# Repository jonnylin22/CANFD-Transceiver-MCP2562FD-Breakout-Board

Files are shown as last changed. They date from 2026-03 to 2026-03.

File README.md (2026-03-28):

# CAN-FD Transceiver MCP2562FD Breakout Board #

This board lays out the Microchip Technology MCP2562FD CAN-FD Transceiver IC onto a board to create an external breakout board style CAN physical layer for MCUs with an embedded CAN controller but no transceiever.  

Exact Reference Manufacturer Product Number: MCP2562FD-E/SN  

## Final Boards 3D Renders ##  
CANFD Breakout with Spring Terminals Top Side  
CANFD Breakout with Spring Terminals Bottom Side

CANFD Breakout with JST-PH3 Connector Top Side
CANFD Breakout with JST-PH3 Connector Bottom Side

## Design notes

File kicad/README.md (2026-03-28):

# Directory for everything KiCad #  

The file named gerbers.zip stores the most up to date generated PCB manufacturing files.  
The folder named version2-with-JST-PH3/ ustilizes a JST-PH3 connector with the same components.

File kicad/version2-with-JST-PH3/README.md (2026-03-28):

# CAN-FD Transceiver Breakout Board #  

This is a board with the same components except that it is routed to a JST-PH3 right angle horizontal connector to allow for use of JST-PH3 cables for the CAN bus

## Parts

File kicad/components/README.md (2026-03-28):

# Component Library for KiCad Schematic and PCB #  

3D models are in models/  
PCB layout footprints are in footprints/  
Schematic design symbols are in symbols/

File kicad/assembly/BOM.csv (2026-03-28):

Reference | Qty | Value | Footprint | Datasheet | Manufacturer_Name | Manufacturer_Part_Number | LCSC_Part_Number
C1,C3 | 2 | 100n | Capacitor_SMD:C_0603_1608Metric_Pad1.08x0.95mm_HandSolder | ~ | Samsung Electro-Mechanics | CL10E104KC8VPNC | C16194197
C2 | 1 | 4.7n | Resistor_SMD:R_0402_1005Metric_Pad0.72x0.64mm_HandSolder | ~ | KEMET | C0402C472J5RACTU | C2167398
D1,D2 | 2 | LED | LED_SMD:LED_0603_1608Metric_Pad1.05x0.95mm_HandSolder | ~ | LITEON | LTST-C191KRKT | C125099
D3 | 1 | CDSOT23-T24CAN | CanFD-Transceiver-FP-Lib:SOT95P230X117-3N | https://www.bourns.com/docs/Product-Datasheets/CDSOT23-T24CAN.pdf | Bourns | CDSOT23-T24CAN
J2 | 1 | 1862042 | CanFD-Transceiver-FP-Lib:1862042 | https://www.phoenixcontact.com/en-us/products/printed-circuit-board-terminal-sptaf-1-2-35-el-1862042?type=pdf | Phoenix Contact | 1862042
R1,R2 | 2 | 60R | Resistor_SMD:R_0402_1005Metric_Pad0.72x0.64mm_HandSolder | ~ | YAGEO | RC0402FR-0762RL | C274896
R3,R4 | 2 | 2k2 | Resistor_SMD:R_0603_1608Metric_Pad0.98x0.95mm_HandSolder | ~ | YAGEO | RC0603FR-072K2L | C114662
U1 | 1 | MCP2562FD-E_SN | CanFD-Transceiver-FP-Lib:SOIC127P600X175-8N | https://ww1.microchip.com/downloads/aemDocuments/documents/OTH/ProductDocuments/DataSheets/20005284A.pdf | Microchip | MCP2562FD-E/SN

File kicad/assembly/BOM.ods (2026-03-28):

Reference | Qty | Value | DNP | Exclude from BOM | Exclude from Board | Footprint | Datasheet | Manufacturer_Name | Manufacturer_Part_Number | LCSC_Part_Number
C1,C3 | 2 | 100n |  |  |  | Capacitor_SMD:C_0603_1608Metric_Pad1.08x0.95mm_HandSolder | ~ | Samsung Electro-Mechanics | CL10E104KC8VPNC | C16194197
C2 | 1 | 4.7n |  |  |  | Resistor_SMD:R_0402_1005Metric_Pad0.72x0.64mm_HandSolder | ~ | KEMET | C0402C472J5RACTU | C2167398
D1,D2 | 2 | LED |  |  |  | LED_SMD:LED_0603_1608Metric_Pad1.05x0.95mm_HandSolder | ~ | LITEON | LTST-C191KRKT | C125099
D3 | 1 | CDSOT23-T24CAN |  |  |  | CanFD-Transceiver-FP-Lib:SOT95P230X117-3N | https://www.bourns.com/docs/Product-Datasheets/CDSOT23-T24CAN.pdf | Bourns | CDSOT23-T24CAN
FD1 | 1 | FIDUCIAL | DNP | Excluded from BOM | Excluded from board | Fiducial:Fiducial_0.5mm_Mask1mm
H1,H3 | 2 | HOLE_2.2mm |  | Excluded from BOM |  | MountingHole:MountingHole_2.2mm_M2_DIN965_Pad_TopBottom | ~
J2 | 1 | 1862042 |  | Excluded from BOM |  | CanFD-Transceiver-FP-Lib:1862042 | https://www.phoenixcontact.com/en-us/products/printed-circuit-board-terminal-sptaf-1-2-35-el-1862042?type=pdf | Phoenix Contact | 1862042
JP1 | 1 | Jumper_2_Small_Open |  | Excluded from BOM |  | Jumper:SolderJumper-2_P1.3mm_Open_RoundedPad1.0x1.5mm | ~
JP2 | 1 | SolderJumper_3_Open |  | Excluded from BOM |  | Jumper:SolderJumper-3_P1.3mm_Open_Pad1.0x1.5mm_NumberLabels | ~
K1 | 1 | HEADER_MALE_6X1 |  | Excluded from BOM |  | Connector_PinHeader_2.54mm:PinHeader_1x06_P2.54mm_Horizontal
R1,R2 | 2 | 60R |  |  |  | Resistor_SMD:R_0402_1005Metric_Pad0.72x0.64mm_HandSolder | ~ | YAGEO | RC0402FR-0762RL | C274896
R3,R4 | 2 | 2k2 |  |  |  | Resistor_SMD:R_0603_1608Metric_Pad0.98x0.95mm_HandSolder | ~ | YAGEO | RC0603FR-072K2L | C114662
U1 | 1 | MCP2562FD-E_SN |  |  |  | CanFD-Transceiver-FP-Lib:SOIC127P600X175-8N | https://ww1.microchip.com/downloads/aemDocuments/documents/OTH/ProductDocuments/DataSheets/20005284A.pdf | Microchip | MCP2562FD-E/SN

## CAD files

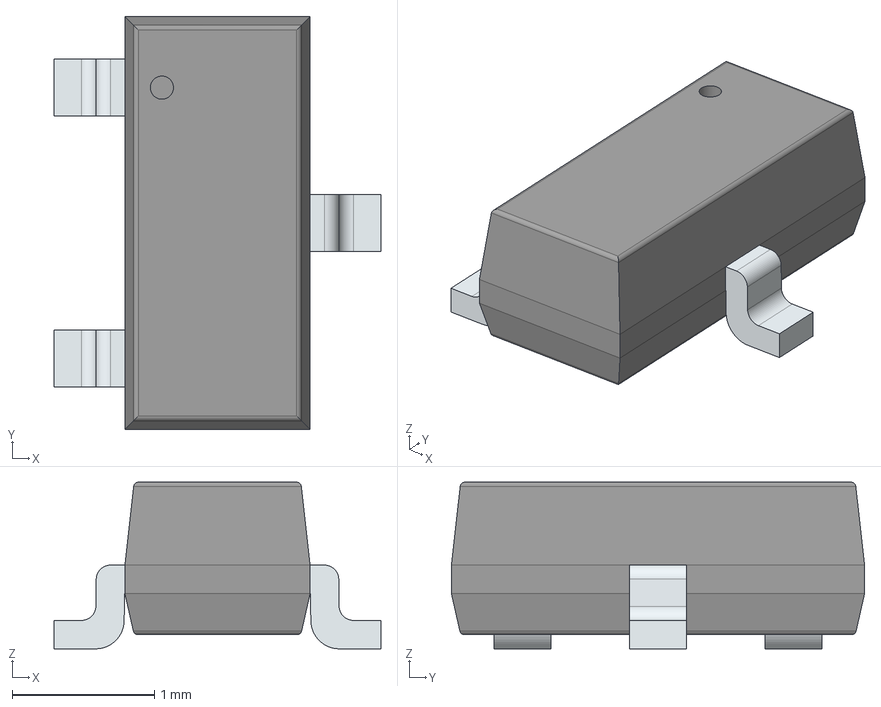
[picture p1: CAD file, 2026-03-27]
kicad/version2-with-JST-PH3/components/models/CDSOT23-T24CAN.stp
2.29 x 2.90 x 1.17 mm
PinsArrayL
FilletPinR

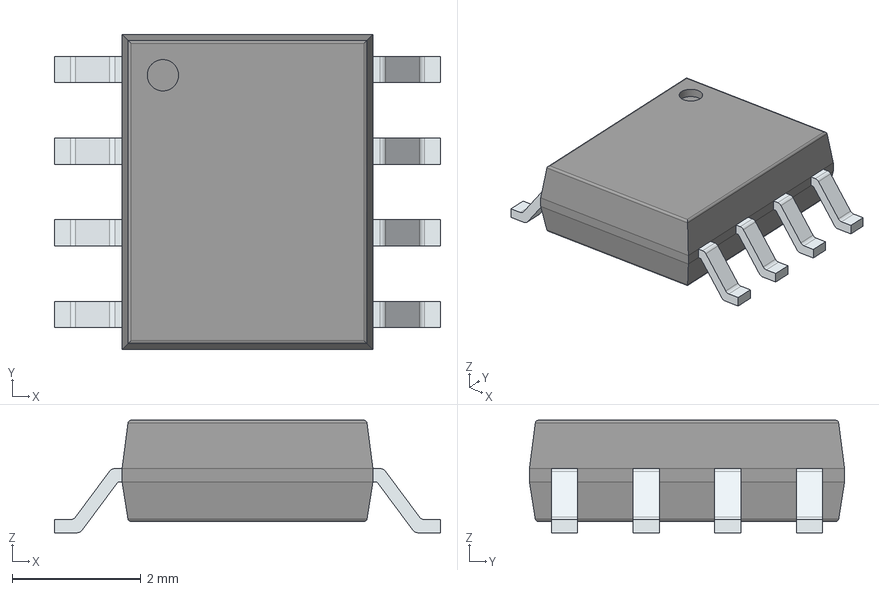
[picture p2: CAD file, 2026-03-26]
kicad/version2-with-JST-PH3/components/models/MCP2562FD-E_SN.stp
6.00 x 4.90 x 1.75 mm
PinsArrayLR

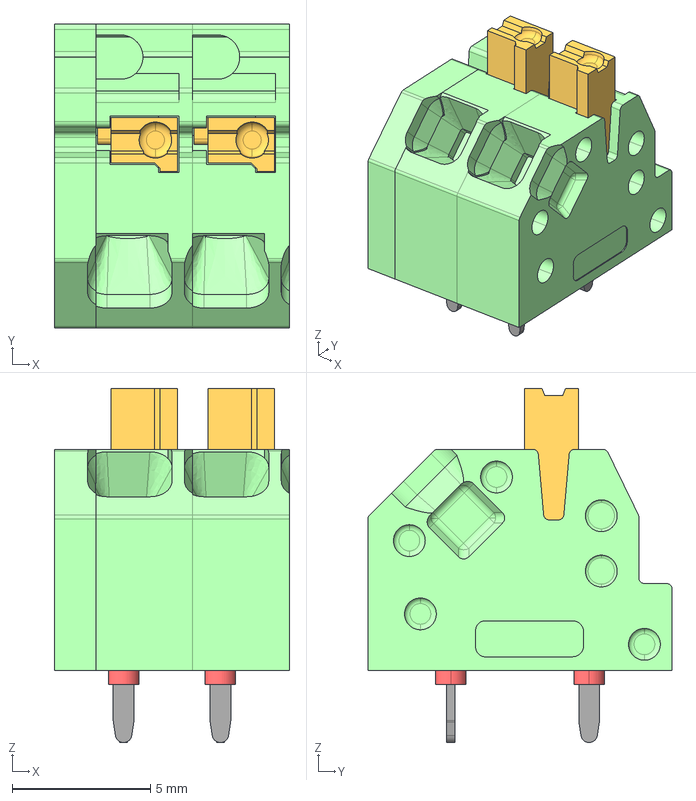
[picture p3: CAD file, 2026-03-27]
kicad/version2-with-JST-PH3/components/models/1862042.stp
8.50 x 11.0 x 12.8 mm
Bohrloch.1.1 x 2
Bohrloch.2 x 2
SPTAF_1-3.5_housing x 2
SPTAF-0-DKL.1

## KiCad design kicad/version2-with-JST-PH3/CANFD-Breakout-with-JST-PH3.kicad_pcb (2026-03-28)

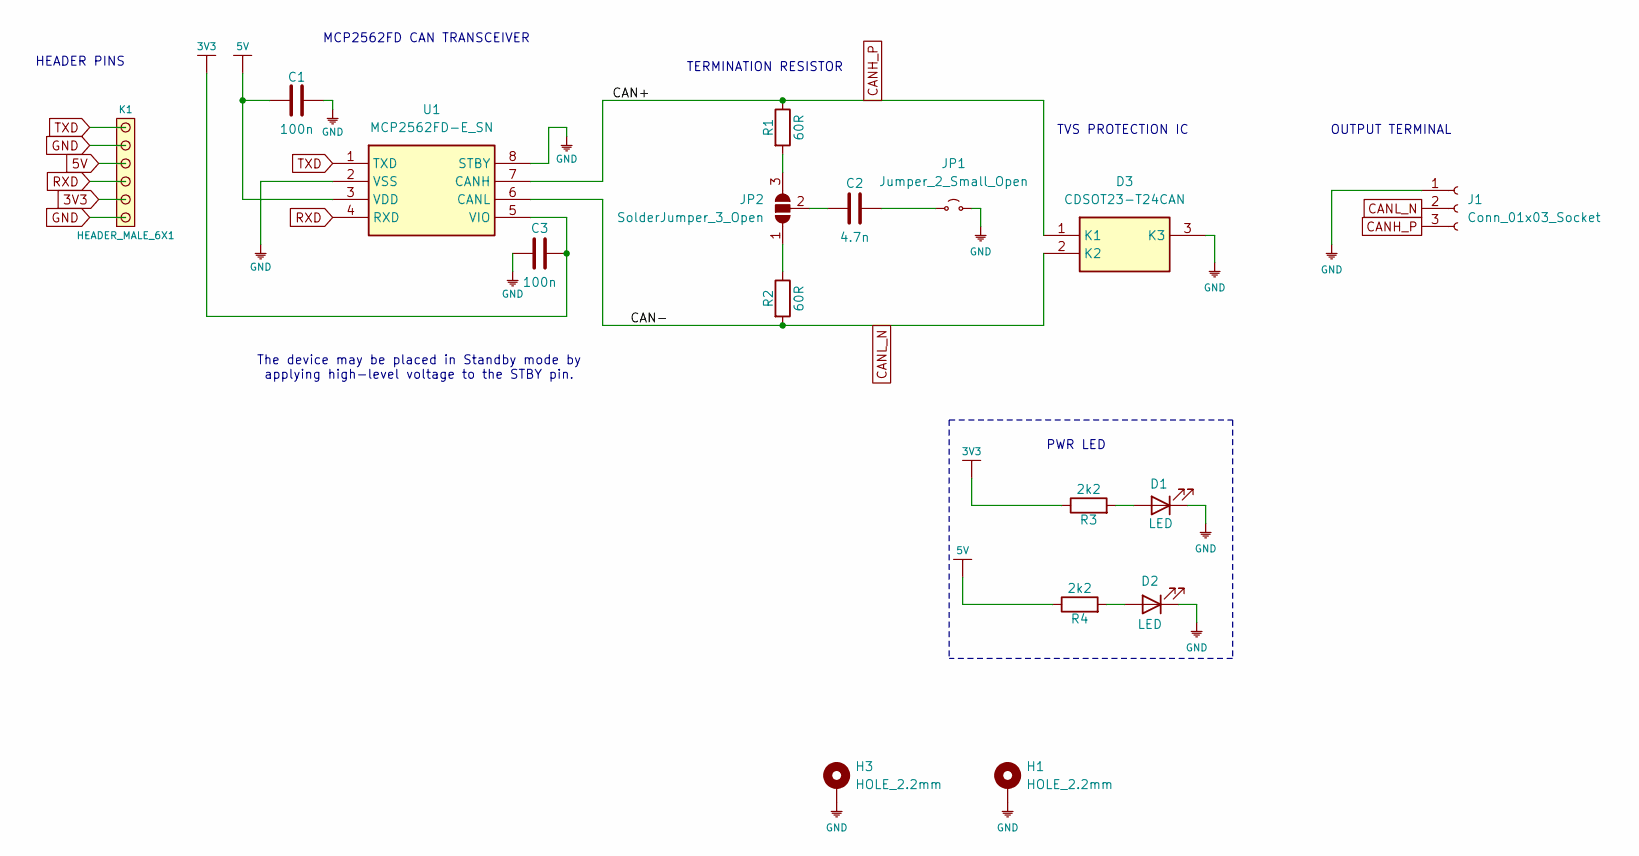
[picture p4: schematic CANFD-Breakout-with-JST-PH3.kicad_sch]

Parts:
C1, C3: 100n; C_0603_1608Metric_Pad1.08x0.95mm_HandSolder; Manufacturer_Part_Number CL10E104KC8VPNC; LCSC_Part_Number C16194197
C2: 4.7n; R_0402_1005Metric_Pad0.72x0.64mm_HandSolder; Manufacturer_Part_Number C0402C472J5RACTU; LCSC_Part_Number C2167398
D1, D2: LED; LED_0603_1608Metric_Pad1.05x0.95mm_HandSolder; Manufacturer_Part_Number LTST-C191KRKT; LCSC_Part_Number C125099
D3: CDSOT23-T24CAN; SOT95P230X117-3N; Mouser Part Number 652-CDSOT23-T24CAN
H1, H3: HOLE_2.2mm; MountingHole_2.2mm_M2_DIN965_Pad_TopBottom
J1: Conn_01x03_Socket; JST_PH_S3B-PH-K_1x03_P2.00mm_Horizontal
JP1: Jumper_2_Small_Open; SolderJumper-2_P1.3mm_Open_RoundedPad1.0x1.5mm
JP2: SolderJumper_3_Open; SolderJumper-3_P1.3mm_Open_Pad1.0x1.5mm_NumberLabels
K1: HEADER_MALE_6X1; PinHeader_1x06_P2.54mm_Horizontal
R1, R2: 60R; R_0402_1005Metric_Pad0.72x0.64mm_HandSolder; Manufacturer_Part_Number RC0402FR-0762RL; LCSC_Part_Number C274896
R3, R4: 2k2; R_0603_1608Metric_Pad0.98x0.95mm_HandSolder; Manufacturer_Part_Number RC0603FR-072K2L; LCSC_Part_Number C114662
U1: MCP2562FD-E_SN; SOIC127P600X175-8N; Mouser Part Number 579-MCP2562FD-E/SN

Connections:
3V3: C3.2, K1.2, R3.1, U1.5 (VIO)
5V: C1.1, K1.4, R4.1, U1.3 (VDD)
CANH_P: D3.1 (K1), J1.3, R1.1, U1.7 (CANH)
CANL_N: D3.2 (K2), J1.2, R2.2, U1.6 (CANL)
GND: C1.2, C3.1, D1.1 (K), D2.1 (K), D3.3 (K3), H1.1, H3.1, J1.1, JP1.2 (B), K1.1, K1.5, U1.2 (VSS), U1.8 (STBY)
unnamed: D1.2 (A), R3.2
unnamed: D2.2 (A), R4.2
unnamed: C2.2, JP1.1 (A)
unnamed: JP2.1 (A), R2.1
unnamed: JP2.3 (B), R1.2
unnamed: C2.1, JP2.2 (C)
RXD: K1.3, U1.4 (RXD)
TXD: K1.6, U1.1 (TXD)

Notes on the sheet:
HEADER PINS
PWR LED
OUTPUT TERMINAL
MCP2562FD CAN TRANSCEIVER
TVS PROTECTION IC
TERMINATION RESISTOR
The device may be placed in Standby mode by applying high-level voltage to the STBY pin.

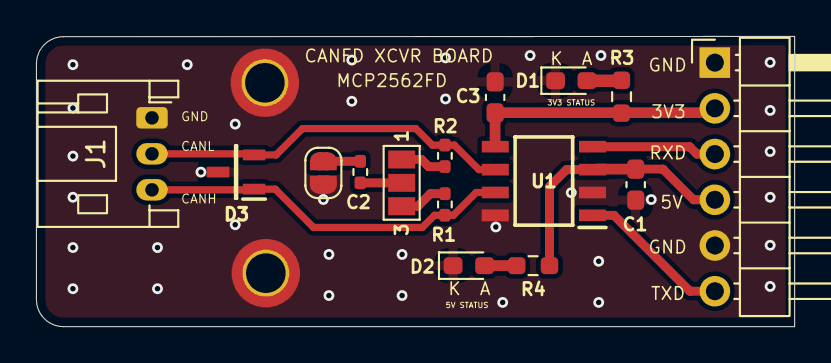
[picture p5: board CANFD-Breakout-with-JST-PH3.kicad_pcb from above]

Board: 2 copper layers, 42.1 x 16.1 mm, 17 parts (0 on the bottom side), 13 nets.

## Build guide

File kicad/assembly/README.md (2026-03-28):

# Files for PCB Assembly #  

The Bill of Materials list is BOM.ods and BOM.csv  
The CPL (centroid) file is the file name CANFD...-top-pos.csv

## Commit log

2026-03-26 setting up project template
    [CANFD-Transceiver-Breakout-Board-MCP2562FD.kicad_pcb, CANFD-Transceiver-Breakout-Board-MCP2562FD.kicad_sch, MCP2562FD-E_SN.stp]
2026-03-26 moved to kicad folder
    [CANFD-Transceiver-Breakout-Board-MCP2562FD.kicad_pcb, CANFD-Transceiver-Breakout-Board-MCP2562FD.kicad_sch, MCP2562FD-E_SN.stp]
2026-03-26 editing schematic
    [CANFD-Transceiver-Breakout-Board-MCP2562FD.kicad_sch]
2026-03-27 finished designing CANFD breakout
    [1862042.stp, CANFD-Transceiver-Breakout-Board-MCP2562FD.kicad_pcb, CANFD-Transceiver-Breakout-Board-MCP2562FD.kicad_sch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]
2026-03-27 edited gitignore
    [1862042.stp, CANFD-Transceiver-Breakout-Board-MCP2562FD.kicad_pcb, CDSOT23-T24CAN.stp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]
2026-03-27 gerber zip
2026-03-27 rename back
    [1862042.stp, CDSOT23-T24CAN.stp, MCP2562FD-E_SN.stp]
2026-03-27 final changes
    [CANFD-Transceiver-Breakout-Board-MCP2562FD.kicad_pcb]
2026-03-28 final revision
    [BOM.ods, CANFD-Transceiver-Breakout-Board-MCP2562FD.kicad_pcb, CANFD-Transceiver-Breakout-Board-MCP2562FD.kicad_sch]
2026-03-28 v2 with jst connector
    [1862042.stp, CANFD-Breakout-with-JST-PH3.kicad_pcb, CANFD-Breakout-with-JST-PH3.kicad_sch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]
2026-03-28 tracking csv files now
    [BOM.csv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]
